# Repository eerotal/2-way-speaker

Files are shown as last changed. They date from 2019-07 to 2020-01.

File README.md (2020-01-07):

Two Way Concrete Speakers
-------------------------

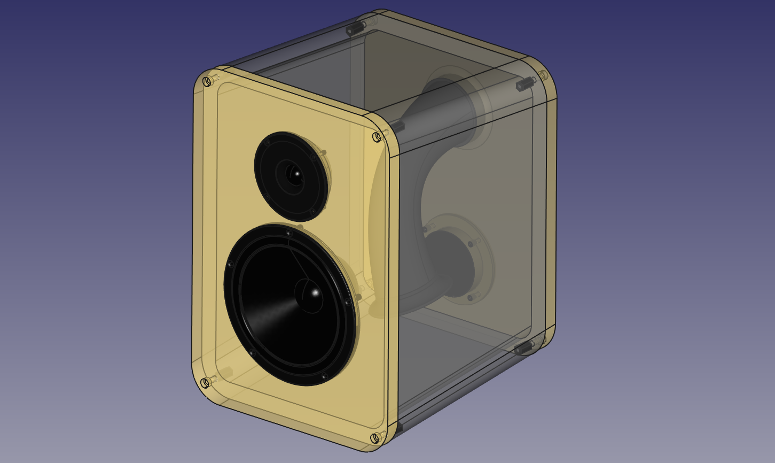
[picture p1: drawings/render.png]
Two Way Speaker


This repository contains all design files for my two way concrete speakers
See the PDF file at `latex/documentation.pdf` for the full documentation.
The PDF file is a concatenated version of all of the exported design files.

The contents of this repository are licensed under the CERN OHL v1.2 license
unless otherwise noted. The full license can be found in the file LICENSE.pdf
in the root of this repository.

License
-------

Copyright Eero Talus 2020.

This documentation describes Open Hardware and is licensed under the CERN OHL
v. 1.2.

You may redistribute and modify this documentation under the terms of the
CERN OHL v.1.2. (http://ohwr.org/cernohl). This documentation is distributed
WITHOUT ANY EXPRESS OR IMPLIED WARRANTY, INCLUDING OF MERCHANTABILITY,
SATISFACTORY QUALITY AND FITNESS FOR A PARTICULAR PURPOSE. Please see the
CERN OHL v.1.2 for applicable conditions.

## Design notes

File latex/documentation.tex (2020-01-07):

\documentclass[10pt]{article}

\usepackage[a4paper,left=20mm, right=20mm, top=20mm, bottom=20mm]{geometry}
\usepackage{pdfpages}
\usepackage{markdown}
\usepackage{multicol}
\usepackage{caption}
\usepackage[none]{hyphenat}

\title{2-way Concrete Speaker Documentation}
\author{Eero Talus}
\date{\today}

\begin{document}
\maketitle
\tableofcontents

\section{License}

\begin{sloppypar}
\noindent
\texttt{Copyright Eero Talus 2020.}\\

\noindent
\texttt{This documentation describes Open Hardware and is licensed under the
CERN OHL v. 1.2.}\\

\noindent
\texttt{You may redistribute and modify this documentation under the terms of
the CERN OHL v.1.2. (http://ohwr.org/cernohl). This documentation is distributed
WITHOUT ANY EXPRESS OR IMPLIED WARRANTY, INCLUDING OF MERCHANTABILITY,
SATISFACTORY QUALITY AND FITNESS FOR A PARTICULAR PURPOSE. Please see the
CERN OHL v.1.2 for applicable conditions.}
\end{sloppypar}

\section{Introduction}

\noindent This PDF contains documentation for my self designed vented two way
speakers. All the design files can be found from the GIT repository at
\url{https://github.com/eerotal/2-way-speaker}. Below is a 3D render of the
speakers.\\

\begin{figure}[htp]
	\centering
	
	\caption{3D render of the speaker.}
\end{figure}

\begin{figure}[htp]
	\centering
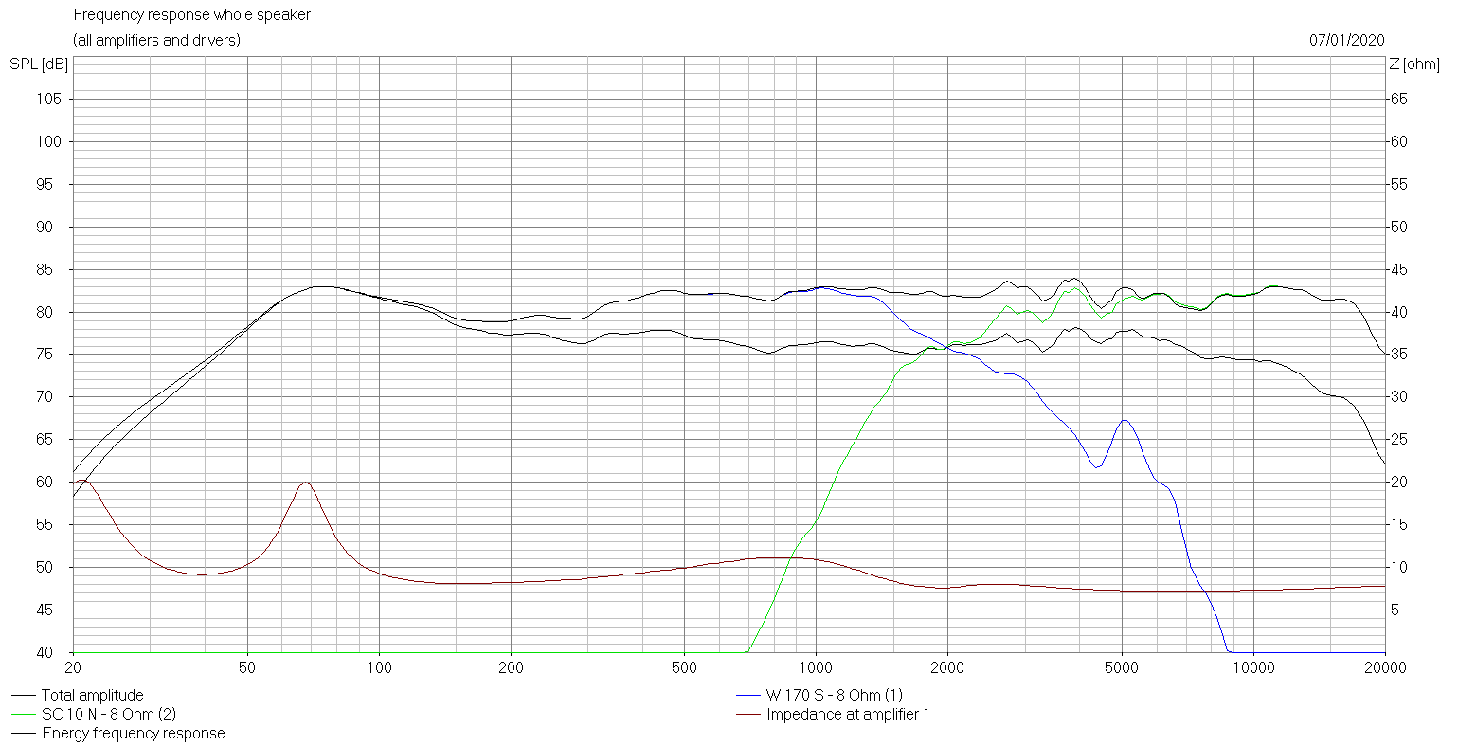
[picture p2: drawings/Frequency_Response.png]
	
	\caption{Speaker frequency response graph.}
\end{figure}

\pagebreak

\noindent The speaker specifications are:

\begin{itemize}
\item Cabinet volume (V): 20 l
\item Cabinet tuning frequenxy (Fb): 42.49 Hz
\item Woofer: Visaton W-170 S 8Ohm
\item Tweeter: Visaton SC-10 N
\end{itemize}

\noindent The speaker cabinet was designed to have a frequency response that's
as flat as possible over the entire bandwidth of the speaker. The cabinet
features a theoretically optimal reflex port designed based on various research
papers on the subject. The cabinet is constructed from concrete and wood to
increase its mass and to improve speaker performance.\\

\noindent The speaker uses a crossover circuit made using third order
Butterworth filters. Speaker impedance and sensitivity matching was also taken
into account while desiging the filter. All design and documentation files were
created using open file formats, tools and technologies.\\

\noindent You can run the shell script \texttt makedocs.sh to generate this
PDF file.

\section{Respository directory structure}

\begin{itemize}
\item 2-way-speaker
    \begin{itemize}
    \item crossover
        \begin{itemize}
        \item KiCad
            \begin{itemize}
            \item \textit{Crossover schematics and PCB design files.}
            \end{itemize}
        \item ngspice
            \begin{itemize}
            \item \textit{NgSpice crossover simulation files.}
            \end{itemize}
        \end{itemize}
    \item docs
        \begin{itemize}
        \item \textit{Documentation files.}
        \end{itemize}
    \item latex
        \begin{itemize}
        \item \textit{LaTeX files for concatenating all documentation files into one PDF.}
        \end{itemize}
    \item math
        \begin{itemize}
        \item \textit{WxMaxima design calculations.}
        \end{itemize}
    \item models
        \begin{itemize}
        \item \textit{FreeCAD 3D design files.}
        \end{itemize}
    \item simulation
        \begin{itemize}
        \item \textit{Visaton Boxsim simulation files.}
        \end{itemize}
    \end{itemize}
\end{itemize}

\section{Software and technologies}

Below is a list of the software and technologies used in this project.

\begin{itemize}
\item KiCad: Crossover electronics design.
\item ngspice: Crossover circuit simulation.
\item FreeCAD: 3D models and mechanical drawings.
\item Boxsim: Speaker simulation.
\item wxMaxima: Design calculations.
\item LaTeX: Documentation
\end{itemize}

\pagebreak
\null
\vfil
\centering\section{Mechanical drawings}
\vfil
\pagebreak
\includepdf[landscape=true]{../drawings/Front_Plate_Drawing.pdf}
\includepdf[landscape=true]{../drawings/Back_Plate_Drawing.pdf}
\includepdf[landscape=true]{../drawings/Shell_Drawing.pdf}
\includepdf[landscape=true]{../drawings/Port_Drawing.pdf}

\pagebreak
\null
\vfil
\centering\section{Crossover schematic and simulation graphs}
\vfil
\pagebreak
\includepdf[landscape=true]{../drawings/Crossover_Schematic.pdf}
\begin{multicols}{2}
	
	
	
	
	
\end{multicols}

\end{document}

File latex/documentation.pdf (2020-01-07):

# 2-way Concrete Speaker Documentation

Eero Talus

January 7, 2020

## Contents

1 License | 1
2 Introduction | 1
3 Respository directory structure | 3
4 Software and technologies | 3
5 Mechanical drawings | 4
6 Crossover schematic and simulation graphs | 9

## 1 License

Copyright Eero Talus 2020.

This documentation describes Open Hardware and is licensed under the CERN OHL v. 1.2.

You may redistribute and modify this documentation under the terms of the CERN OHL v.1.2. (http://ohwr.org/cernohl). This documentation is distributed WITHOUT ANY EXPRESS OR IMPLIED WARRANTY, INCLUDING OF MERCHANTABILITY, SATISFACTORY QUALITY AND FITNESS FOR A PARTICULAR PURPOSE. Please see the CERN OHL v.1.2 for applicable conditions.

## 2 Introduction

This PDF contains documentation for my self designed vented two way speakers. All the design files can be found from the GIT repository at https://github.com/eerotal/2-way-speaker. Below is a 3D render of the speakers.

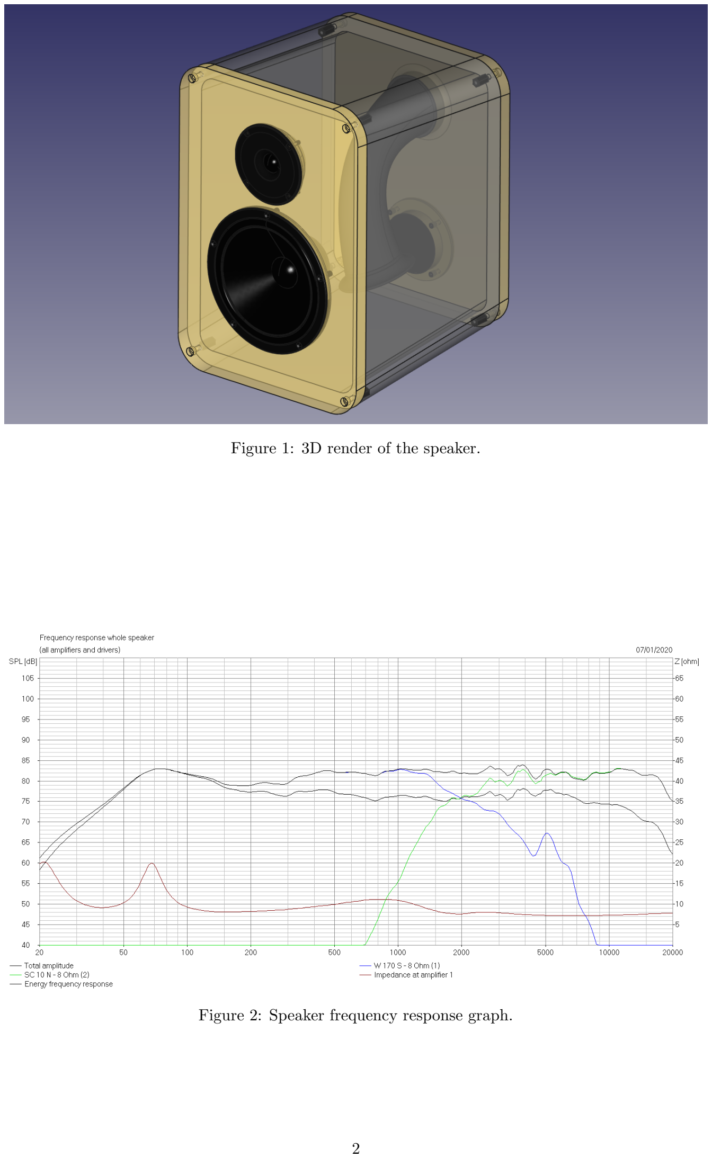
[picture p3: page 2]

Figure 1: 3D render of the speaker.

Figure 2: Speaker frequency response graph.

The speaker specifications are:

- Cabinet volume (V): 20 l
- Cabinet tuning frequenxy (Fb): 42.49 Hz
- Woofer: Visaton W-170 S 8Ohm
- Tweeter: Visaton SC-10 N

The speaker cabinet was designed to have a frequency response that’s as flat as possible over the entire bandwidth of the speaker. The cabinet features a theoretically optimal reflex port designed based on various research papers on the subject. The cabinet is constructed from concrete and wood to increase its mass and to improve speaker performance.

The speaker uses a crossover circuit made using third order Butterworth filters. Speaker impedance and sensitivity matching was also taken into account while desiging the filter. All design and documentation files were created using open file formats, tools and technologies.

You can run the shell script makedocs.sh to generate this PDF file.

## 3 Respository directory structure

- 2-way-speaker

– crossover
∗ KiCad
- Crossover schematics and PCB design files. ∗ ngspice
- NgSpice crossover simulation files.

– docs
∗ Documentation files.

– latex
∗ LaTeX files for concatenating all documentation files into one PDF.

– math
∗ WxMaxima design calculations.

– models
∗ FreeCAD 3D design files.

– simulation
∗ Visaton Boxsim simulation files.

## 4 Software and technologies

Below is a list of the software and technologies used in this project.

- KiCad: Crossover electronics design.
- ngspice: Crossover circuit simulation.
- FreeCAD: 3D models and mechanical drawings.
- Boxsim: Speaker simulation.
- wxMaxima: Design calculations.
- LaTeX: Documentation

## 5 Mechanical drawings

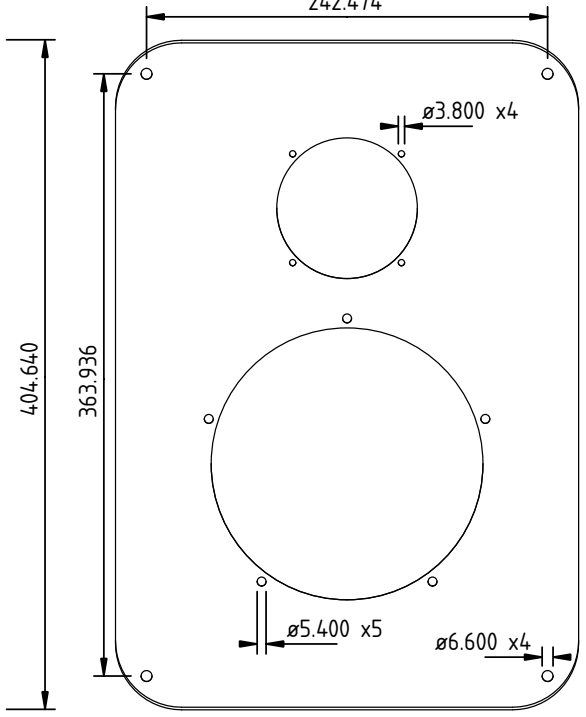
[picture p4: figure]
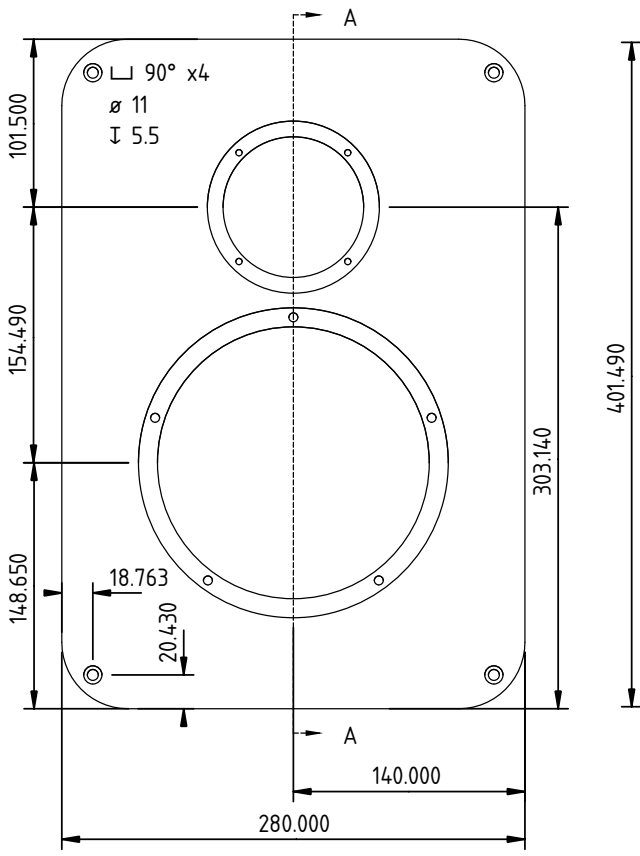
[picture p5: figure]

95.0

18.000

242.474

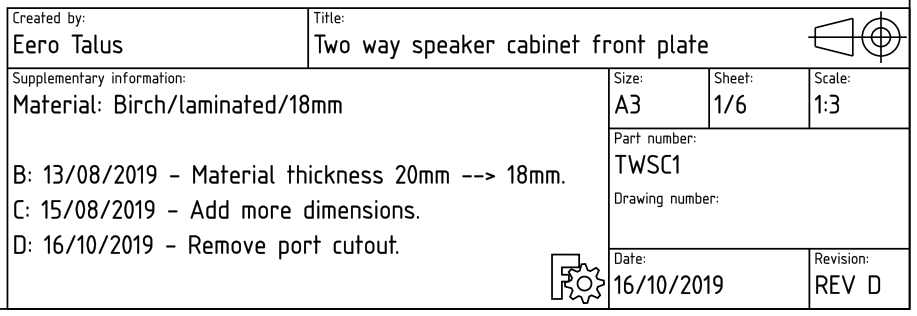
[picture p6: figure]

3D - 1:8

(*1) Tweeter mount holes (M3) are evenly spaced on a ø93.00mm circle. (*2) Woofer mount holes (M4) are evenly spaced on a ø175.80mm circle. (*3) Port cutout edges filleted with radius 8.00mm.
(*4) Front plate perimeter filleted with radius 2.00mm.
(*5) Front plate corner radius 40.00mm.

# Section A - A

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
7.000

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
3.000

Copyright Eero Talus 2019
This documentation describes Open Hardware and is licensed under the CERN OHL v. 1.2.
You may redistribute and modify this documentation under the terms of the CERN OHL v.1.2. (http://ohwr.org/cernohl). This documentation is distributed WITHOUT ANY EXPRESS OR IMPLIED WARRANTY, INCLUDING OF MERCHANTABILITY, SATISFACTORY QUALITY AND FITNESS FOR A PARTICULAR PURPOSE. Please see the CERN OHL v.1.2 for applicable conditions.

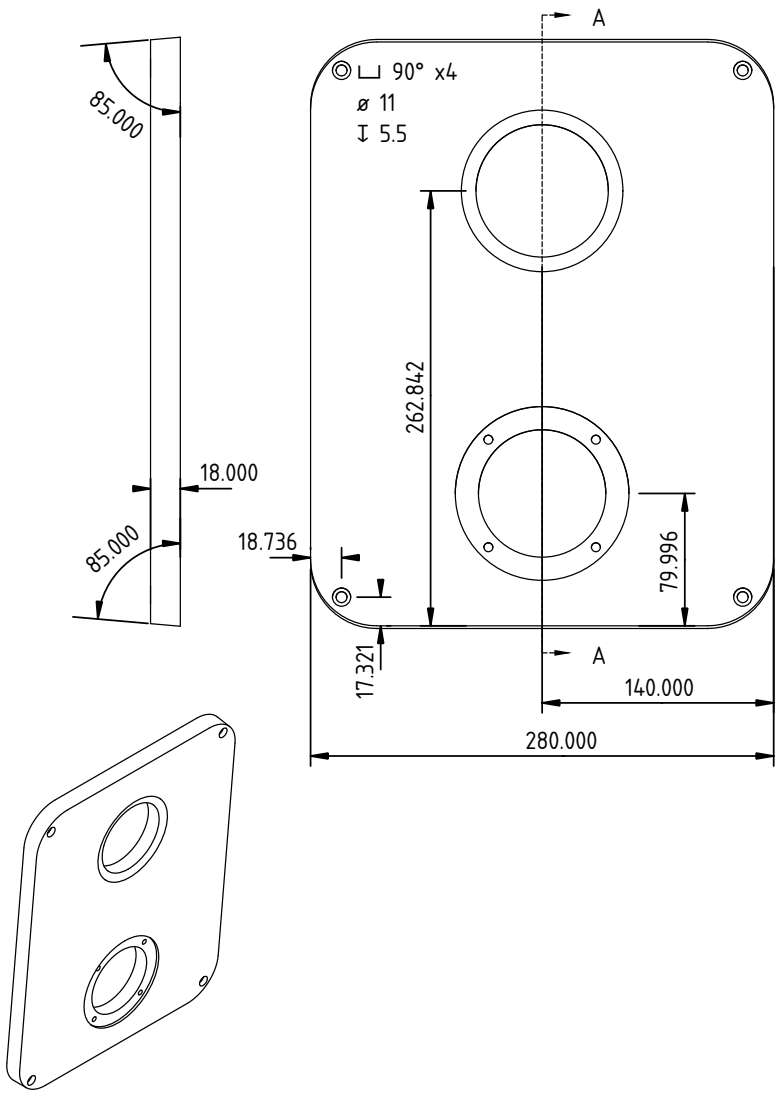
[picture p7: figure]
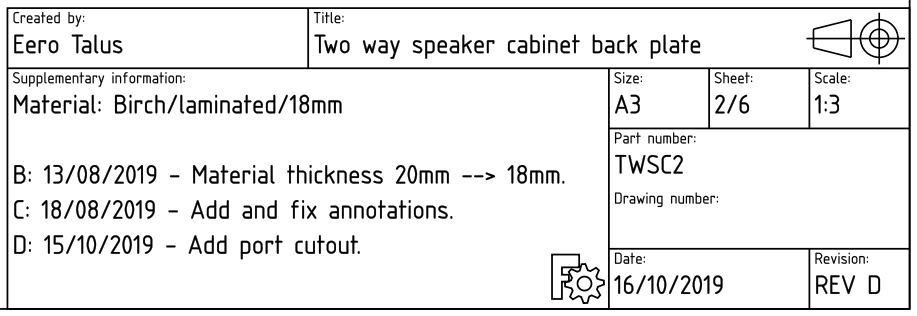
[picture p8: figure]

3D - 1:5

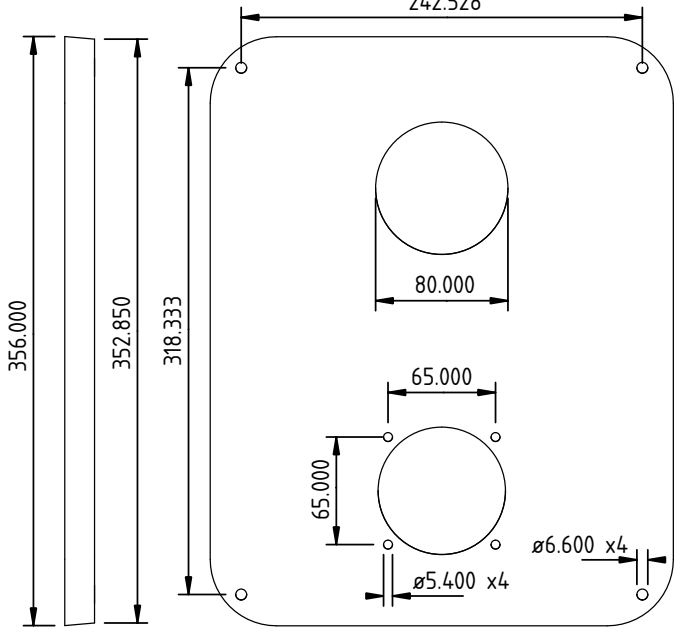
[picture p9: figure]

242.528

(*1) Connector terminal mount holes (M3) are evenly spaced on a ø91.92mm circle.

# Section A - A

18.000

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
3.000

R15.000

(*2) Back plate perimeter filleted with radius 2.00mm. (*3) Back plate corner radius 40.00mm.

Copyright Eero Talus 2019
This documentation describes Open Hardware and is licensed under the CERN OHL v. 1.2.
You may redistribute and modify this documentation under the terms of the CERN OHL v.1.2. (http://ohwr.org/cernohl). This documentation is distributed WITHOUT ANY EXPRESS OR IMPLIED WARRANTY, INCLUDING OF MERCHANTABILITY, SATISFACTORY QUALITY AND FITNESS FOR A PARTICULAR PURPOSE. Please see the CERN OHL v.1.2 for applicable conditions.

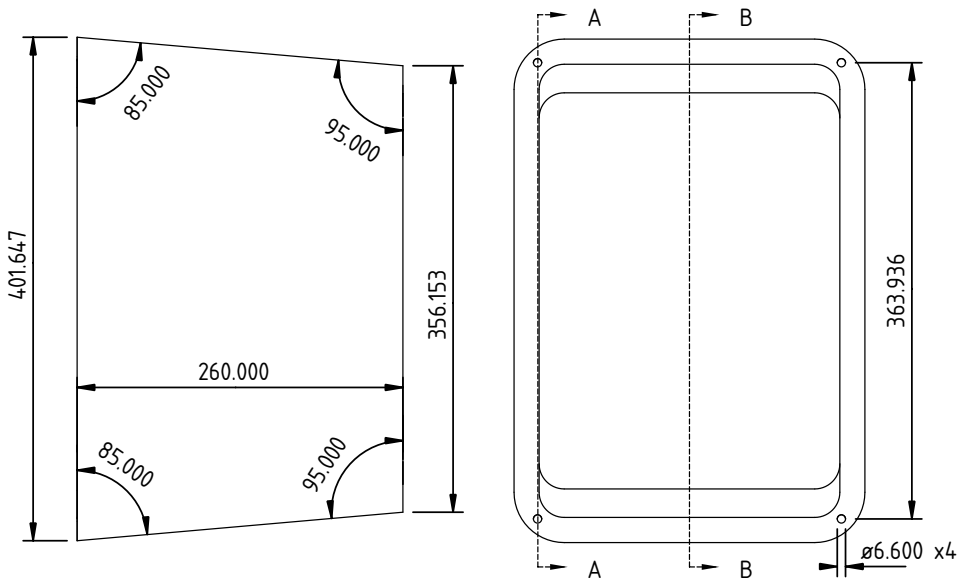
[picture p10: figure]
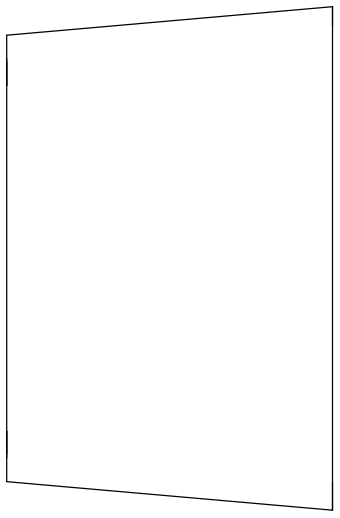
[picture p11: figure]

ø6.600 X4

3

6

3.9

3

6

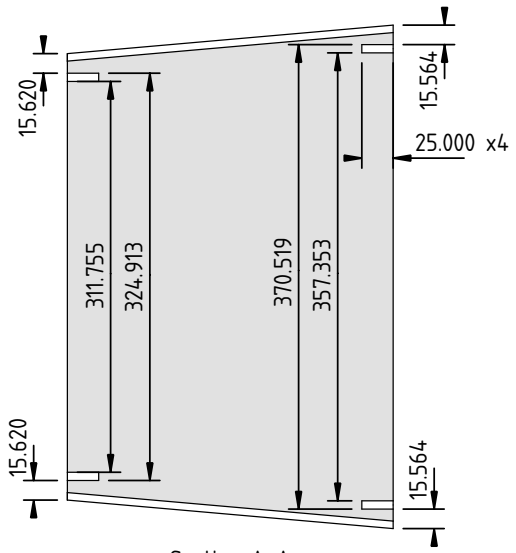
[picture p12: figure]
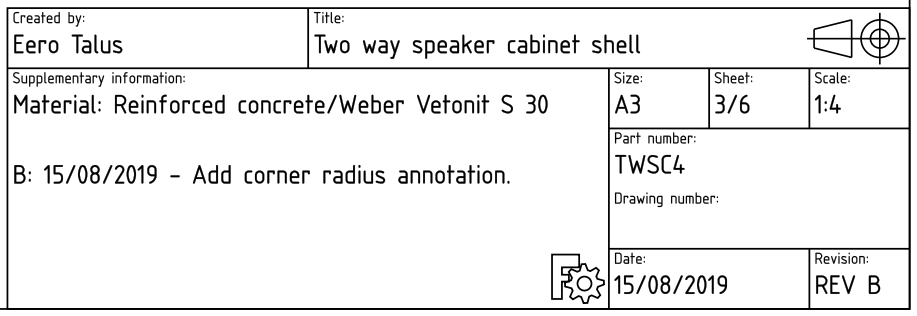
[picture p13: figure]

# Section A-A

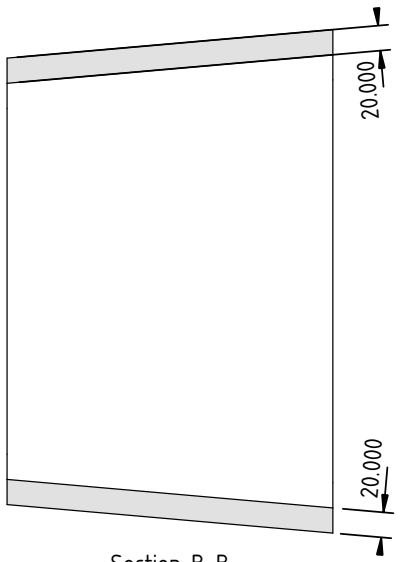
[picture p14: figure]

# Section B-B

3D - 1:8

(*1) Shell corner radius 40.00mm outside and 20.00mm inside.

Copyright Eero Talus 2019
This documentation describes Open Hardware and is licensed under the CERN OHL v. 1.2.
You may redistribute and modify this documentation under the terms of the CERN OHL v.1.2. (http://ohwr.org/cernohl). This documentation is distributed WITHOUT ANY EXPRESS OR IMPLIED WARRANTY, INCLUDING OF MERCHANTABILITY, SATISFACTORY QUALITY AND FITNESS FOR A PARTICULAR PURPOSE. Please see the CERN OHL v.1.2 for applicable conditions.

# (*1) The reflex port is printed in four pieces. Both flares are printed separetely and the main tube is split into two

pieces. These are then glued together after printing.

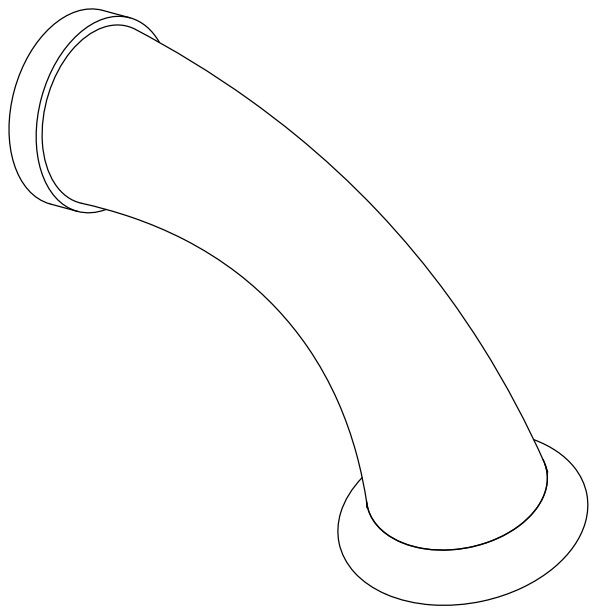
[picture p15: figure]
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

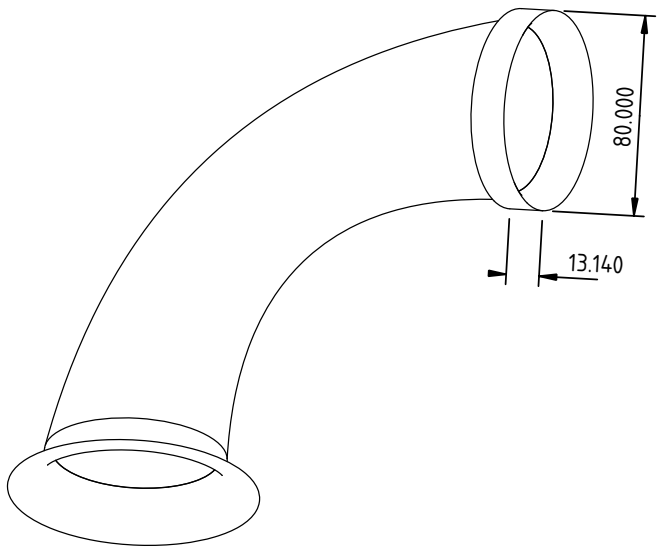
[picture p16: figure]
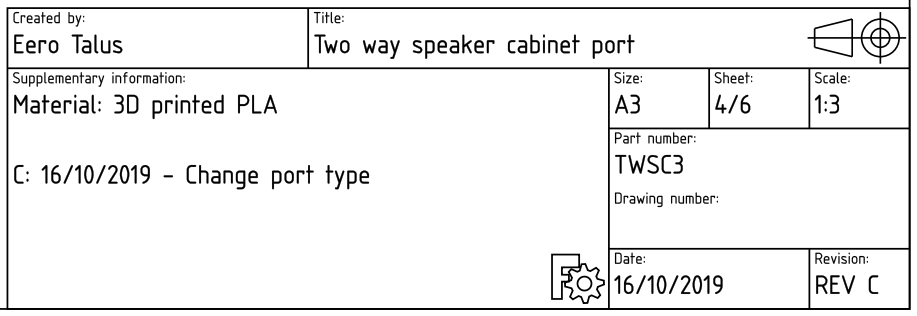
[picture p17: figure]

## 6 Crossover schematic and simulation graphs

H4 C2

## 10uH2 H1

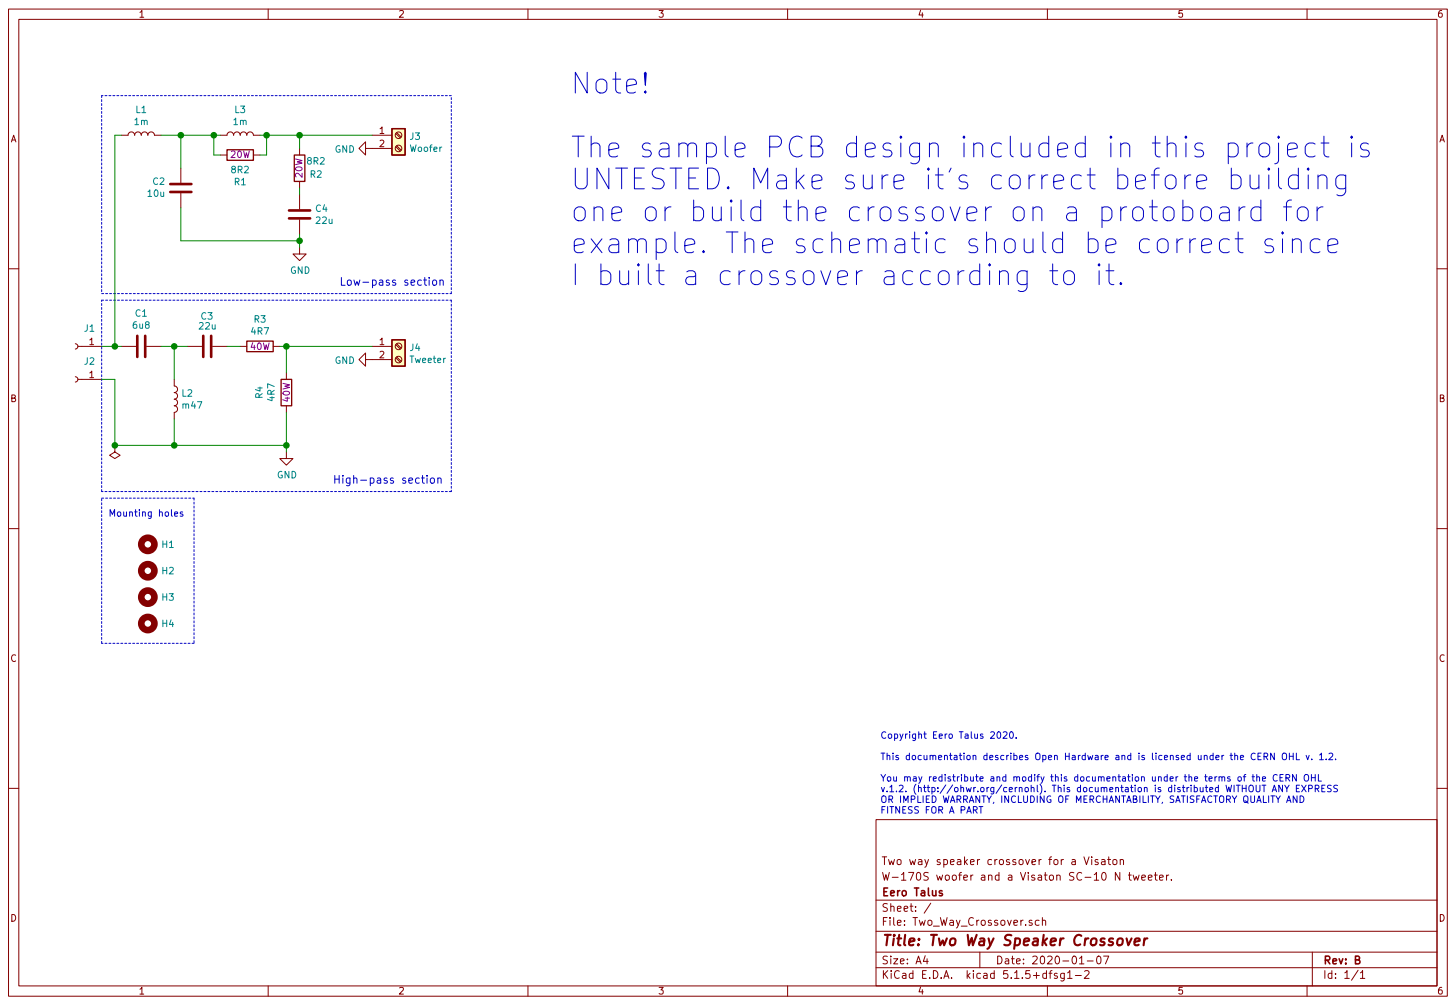
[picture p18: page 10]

The sample PCB design included in this project is
UNTESTED. Make sure it's correct before building
one or build the crossover on a protoboard for
example. The schematic should be correct since
I built a crossover according to it.

This documentation describes Open Hardware and is licensed under the CERN OHL v. 1.2.

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

Id: 1/1 Title: Two Way Speaker Crossover

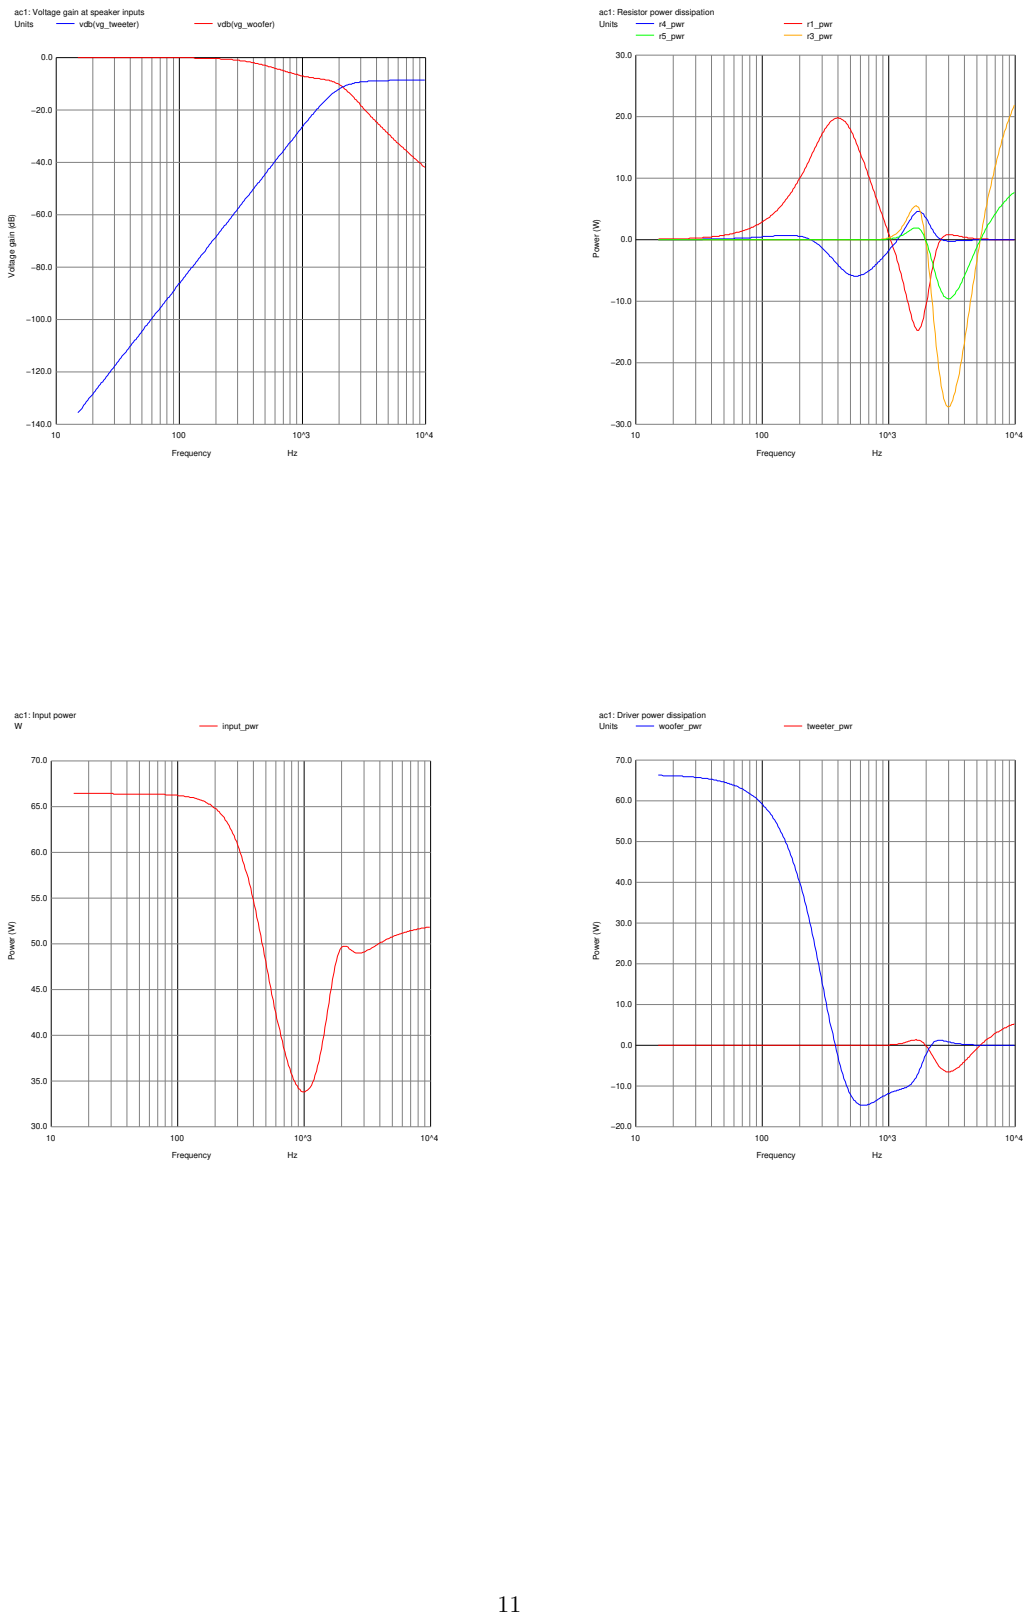
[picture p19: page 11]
Frequency; Units; vdb(vg_tweeter); vdb(vg_woofer); Power (W); ac1: Input power; input_pwr; r4_pwr; r1_pwr; r5_pwr; r3_pwr; woofer_pwr; tweeter_pwr

ac1: Voltage gain at speaker inputs

ac1: Resistor power dissipation

Voltage gain (dB)

ac1: Driver power dissipation

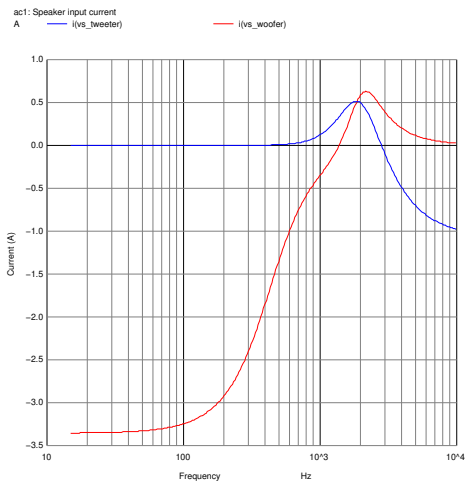
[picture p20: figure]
Frequency; Current (A); ac1: Speaker input current; i(vs_tweeter); i(vs_woofer)

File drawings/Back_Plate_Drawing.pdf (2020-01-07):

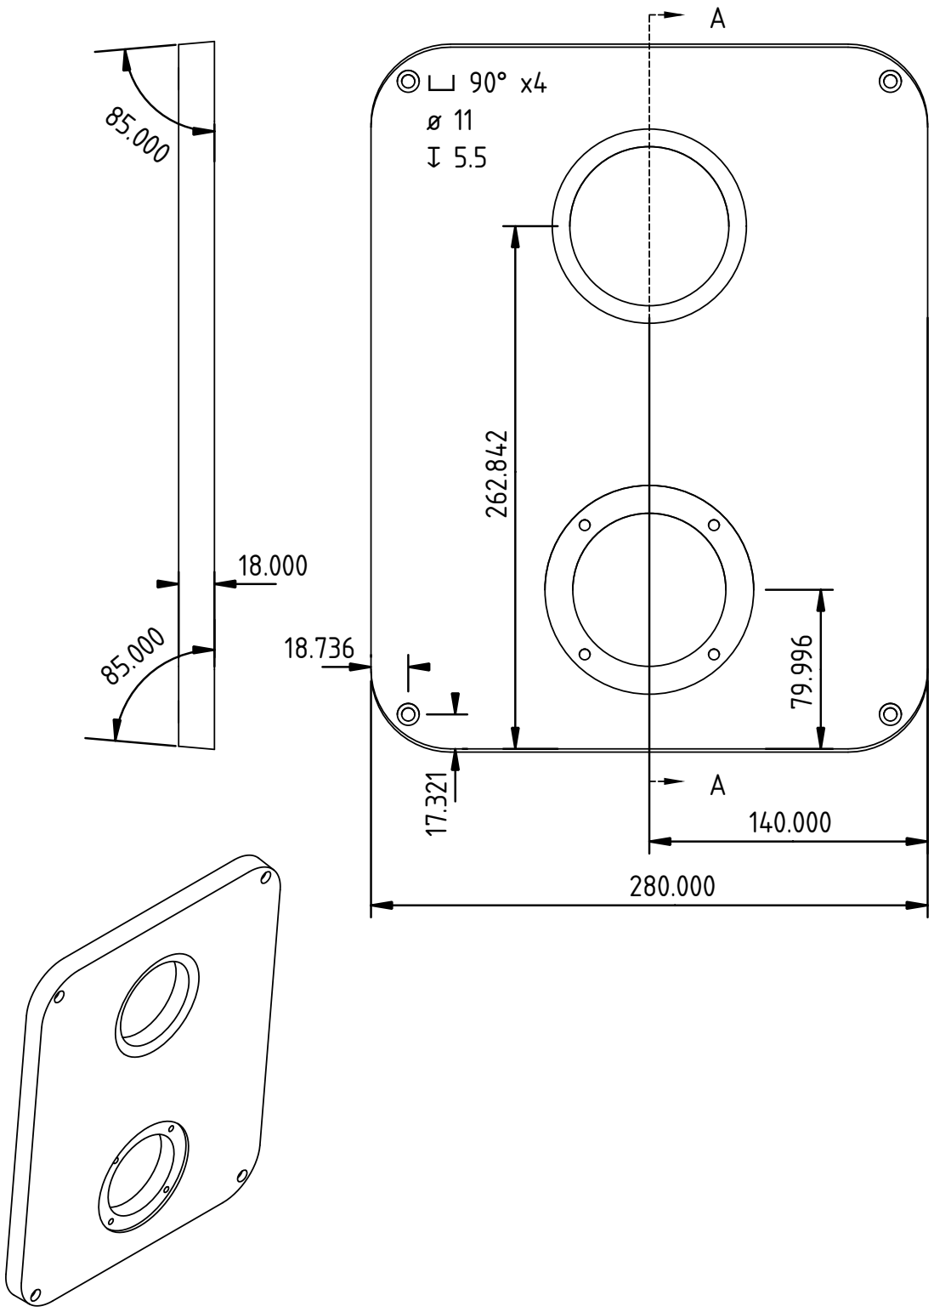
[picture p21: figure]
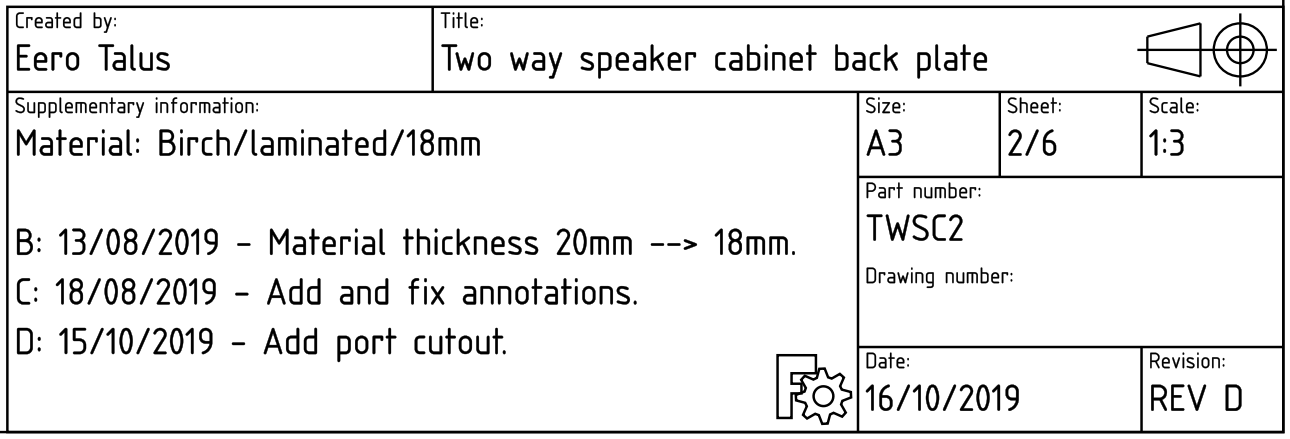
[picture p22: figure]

3D - 1:5

242.528

(*1) Connector terminal mount holes (M3) are evenly spaced on a ø91.92mm circle.

## Section A - A

18.000

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
3.000

R15.000

(*2) Back plate perimeter filleted with radius 2.00mm. (*3) Back plate corner radius 40.00mm.

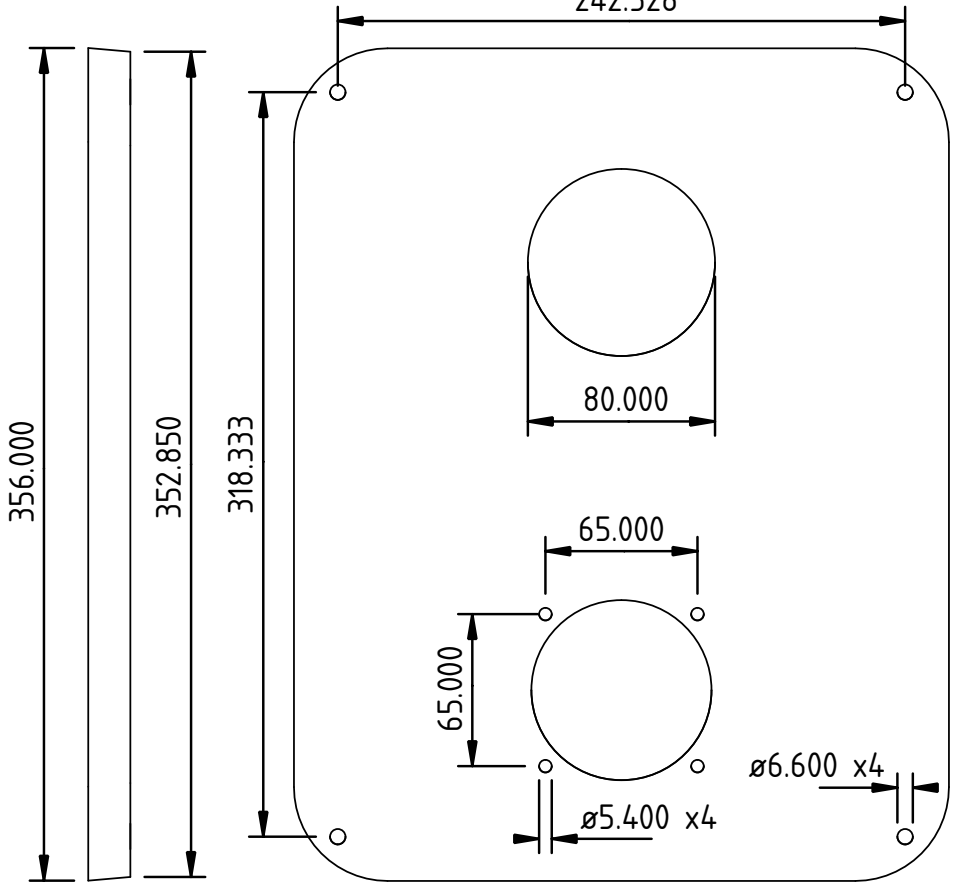
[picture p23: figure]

Copyright Eero Talus 2019
This documentation describes Open Hardware and is licensed under the CERN OHL v. 1.2.
You may redistribute and modify this documentation under the terms of the CERN OHL v.1.2. (http://ohwr.org/cernohl). This documentation is distributed WITHOUT ANY EXPRESS OR IMPLIED WARRANTY, INCLUDING OF MERCHANTABILITY, SATISFACTORY QUALITY AND FITNESS FOR A PARTICULAR PURPOSE. Please see the CERN OHL v.1.2 for applicable conditions.

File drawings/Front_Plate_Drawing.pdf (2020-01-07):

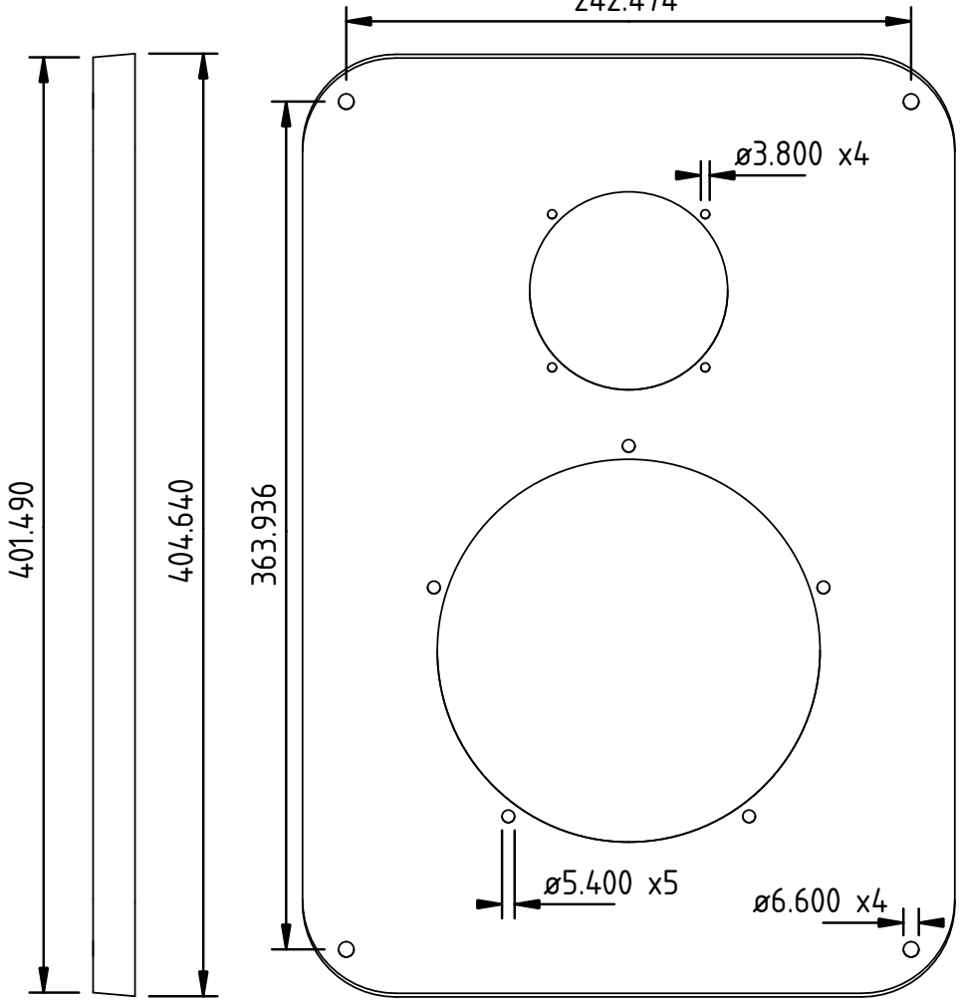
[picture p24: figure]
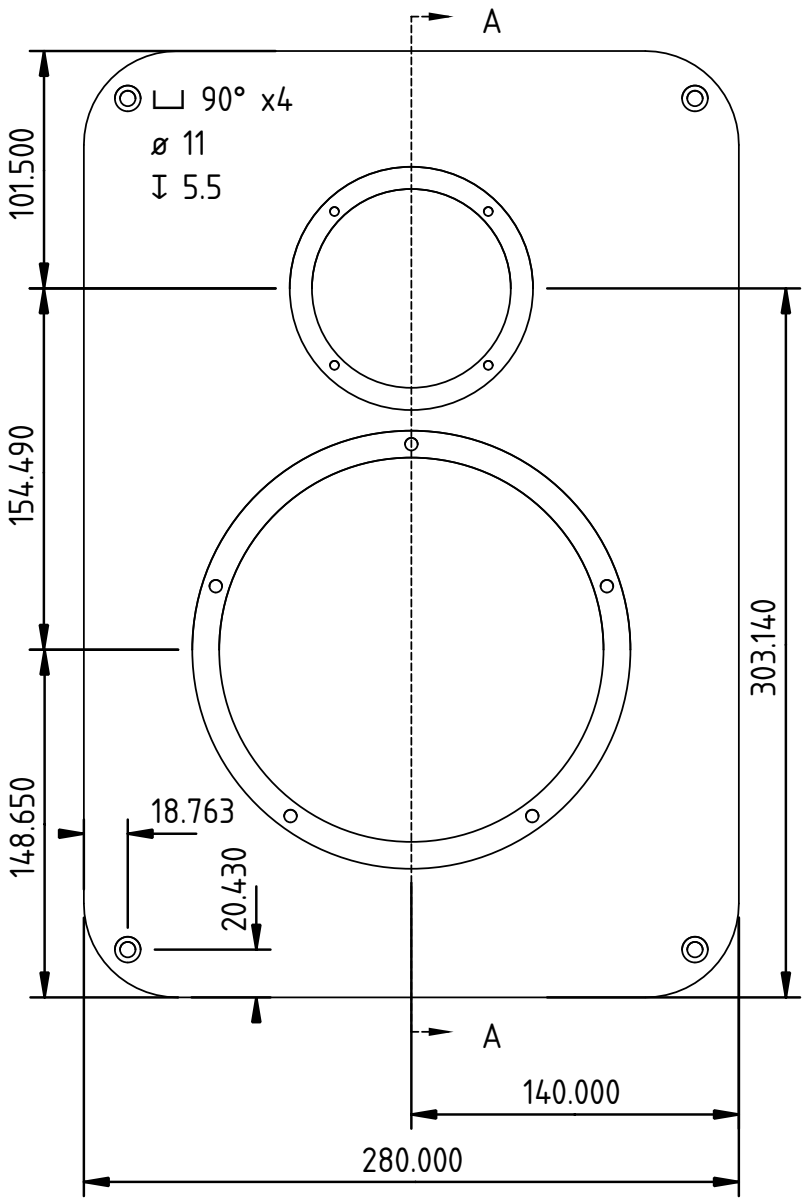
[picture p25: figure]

95.0

18.000

242.474


3D - 1:8

(*1) Tweeter mount holes (M3) are evenly spaced on a ø93.00mm circle. (*2) Woofer mount holes (M4) are evenly spaced on a ø175.80mm circle. (*3) Port cutout edges filleted with radius 8.00mm.
(*4) Front plate perimeter filleted with radius 2.00mm.
(*5) Front plate corner radius 40.00mm.

## Section A - A

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
7.000

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
3.000

Copyright Eero Talus 2019
This documentation describes Open Hardware and is licensed under the CERN OHL v. 1.2.
You may redistribute and modify this documentation under the terms of the CERN OHL v.1.2. (http://ohwr.org/cernohl). This documentation is distributed WITHOUT ANY EXPRESS OR IMPLIED WARRANTY, INCLUDING OF MERCHANTABILITY, SATISFACTORY QUALITY AND FITNESS FOR A PARTICULAR PURPOSE. Please see the CERN OHL v.1.2 for applicable conditions.

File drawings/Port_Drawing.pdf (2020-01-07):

## (*1) The reflex port is printed in four pieces. Both flares are printed separetely and the main tube is split into two

pieces. These are then glued together after printing.


Copyright Eero Talus 2019
This documentation describes Open Hardware and is licensed under the CERN OHL v. 1.2.
You may redistribute and modify this documentation under the terms of the CERN OHL v.1.2. (http://ohwr.org/cernohl). This documentation is distributed WITHOUT ANY EXPRESS OR IMPLIED WARRANTY, INCLUDING OF MERCHANTABILITY, SATISFACTORY QUALITY AND FITNESS FOR A PARTICULAR PURPOSE. Please see the CERN OHL v.1.2 for applicable conditions.


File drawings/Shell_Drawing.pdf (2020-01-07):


ø6.600 X4


3

6

3.9

3

6


## Section A-A


## Section B-B

3D - 1:8

(*1) Shell corner radius 40.00mm outside and 20.00mm inside.

Copyright Eero Talus 2019
This documentation describes Open Hardware and is licensed under the CERN OHL v. 1.2.
You may redistribute and modify this documentation under the terms of the CERN OHL v.1.2. (http://ohwr.org/cernohl). This documentation is distributed WITHOUT ANY EXPRESS OR IMPLIED WARRANTY, INCLUDING OF MERCHANTABILITY, SATISFACTORY QUALITY AND FITNESS FOR A PARTICULAR PURPOSE. Please see the CERN OHL v.1.2 for applicable conditions.

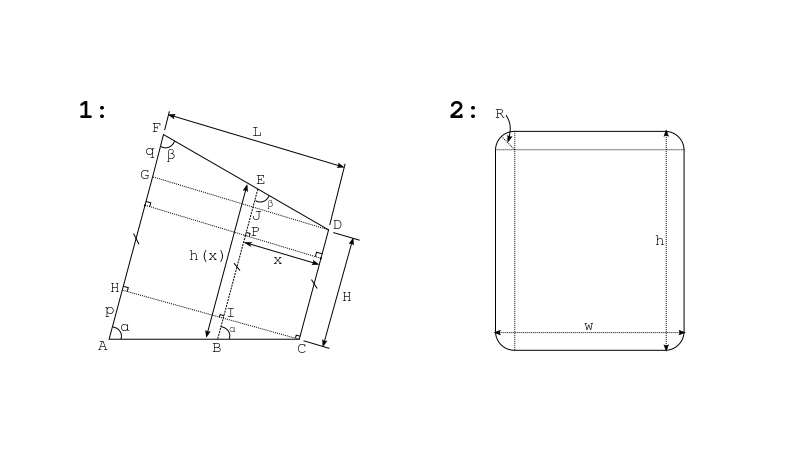
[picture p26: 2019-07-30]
math/drawing.png

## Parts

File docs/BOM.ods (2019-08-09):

Part | Value | Qty | €/pc. | €/tot |  | Ordered
Monacor ST-960GM | N/A | 1 | 5.95000 | 5.9500 | € | Y
Visaton W-170 S 8ohm | N/A | 1 | 36.00000 | 36.0000 | € | Y
Visaton SC-10 N | N/A | 1 | 19.00000 | 19.0000 | € | Y
Bossard BN1054/M4 | N/A | 9 | 0.19390 | 1.7451 | € | N
Bossard BN1054/M3 | N/A | 4 | 0.09440 | 0.3776 | € | N
Visaton 4986 | 1mH | 2 | 4.13000 | 8.2600 | € | N
Visaton 4993 | 0.47mH | 1 | 3.46000 | 3.4600 | € | N
Wima MKS4C051005F00KSSD | 10uF | 2 | 2.20000 | 4.4000 | € | N
Wima MKS4D052206F00KSSD | 22uF | 1 | 4.21500 | 4.2150 | € | N
Wima MKS4D046806B00KSSD | 6.8uF | 1 | 1.81500 | 1.8150 | € | N
Royal Ohm PRW020JW82JB00 | 8.2Ohm | 6 | 0.54170 | 3.2502 | € | N
Total |  |  |  | 88.4729 | €
Total for two |  |  |  | 176.9458 | €

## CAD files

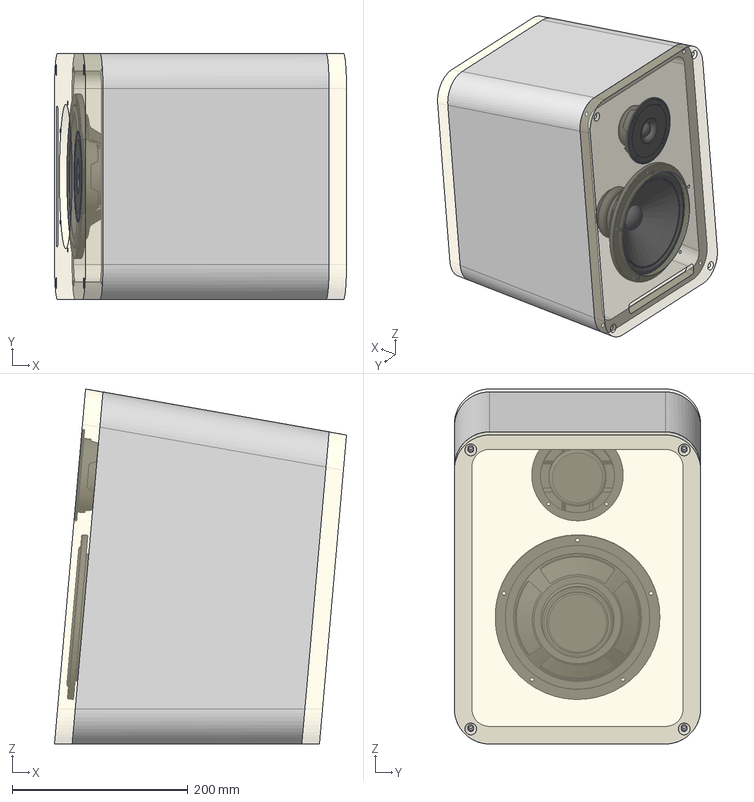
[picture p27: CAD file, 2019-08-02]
model.FCStd
331.9 x 280.0 x 403.4 mm
Front_plate
Back_plate
Port
m6_long_bolt_body003
m6_long_bolt_body002
m6_long_bolt_body001
m6_long_bolt_body
Visaton_W-170_S_Metalwork
Visaton_W-170_S_Cone
Visaton_SC-10_N_Body
Visaton_SC-10_N_Dome

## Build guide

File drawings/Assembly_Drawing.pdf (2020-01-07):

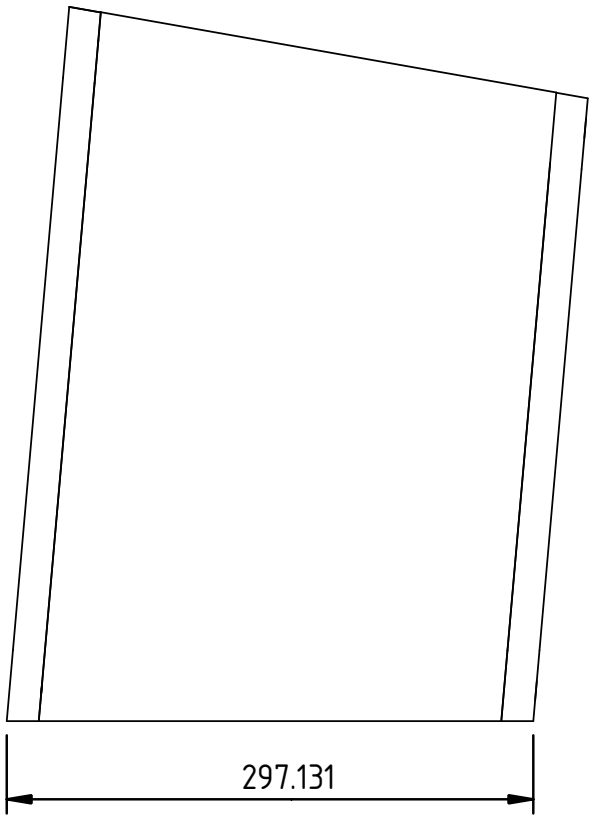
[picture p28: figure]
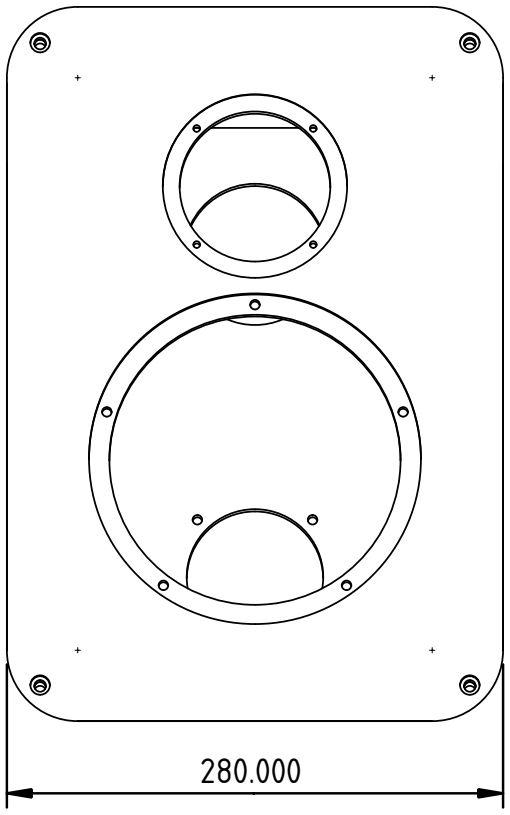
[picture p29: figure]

297.131 280.000

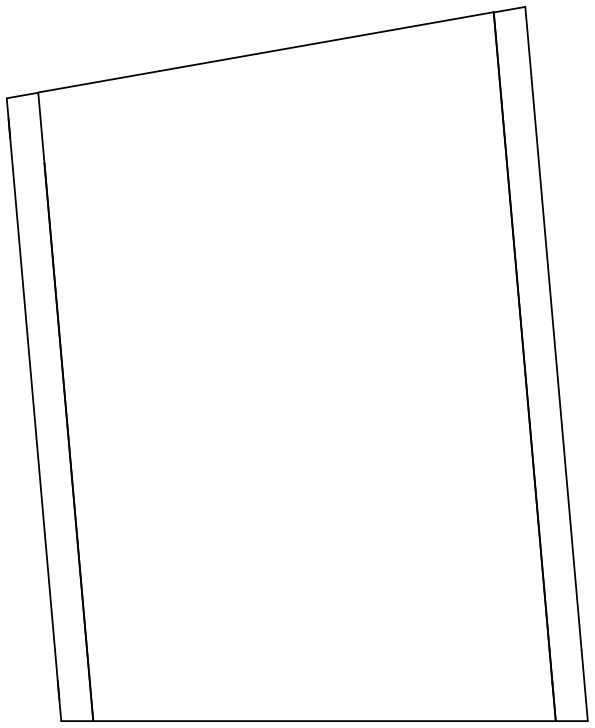
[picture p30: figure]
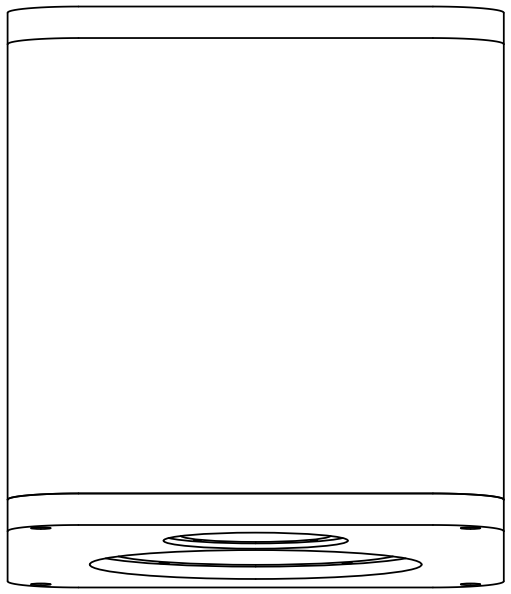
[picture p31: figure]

Copyright Eero Talus 2019

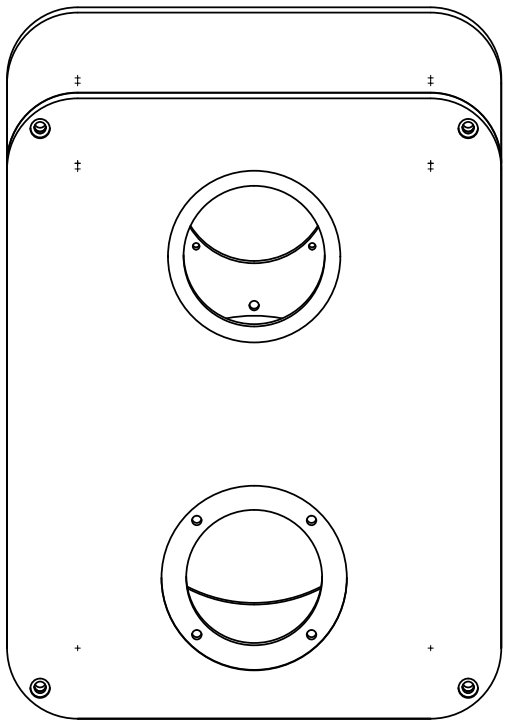
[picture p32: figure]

This documentation describes Open Hardware and is licensed under the CERN OHL v. 1.2.
You may redistribute and modify this documentation under the terms of the CERN OHL v.1.2. (http://ohwr.org/cernohl). This documentation is distributed WITHOUT ANY EXPRESS OR IMPLIED WARRANTY, INCLUDING OF MERCHANTABILITY, SATISFACTORY QUALITY AND FITNESS FOR A PARTICULAR PURPOSE. Please see the CERN OHL v.1.2 for applicable conditions.

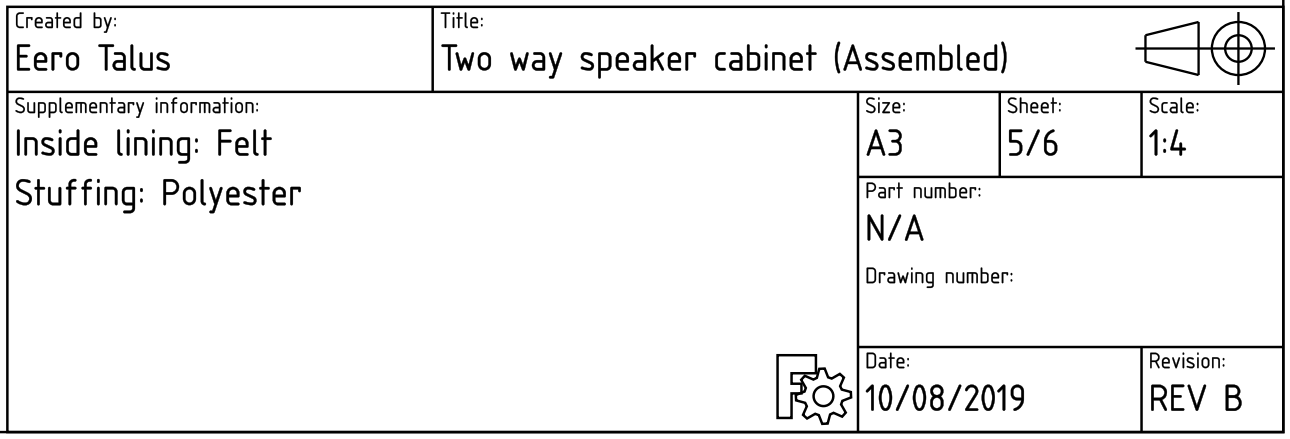
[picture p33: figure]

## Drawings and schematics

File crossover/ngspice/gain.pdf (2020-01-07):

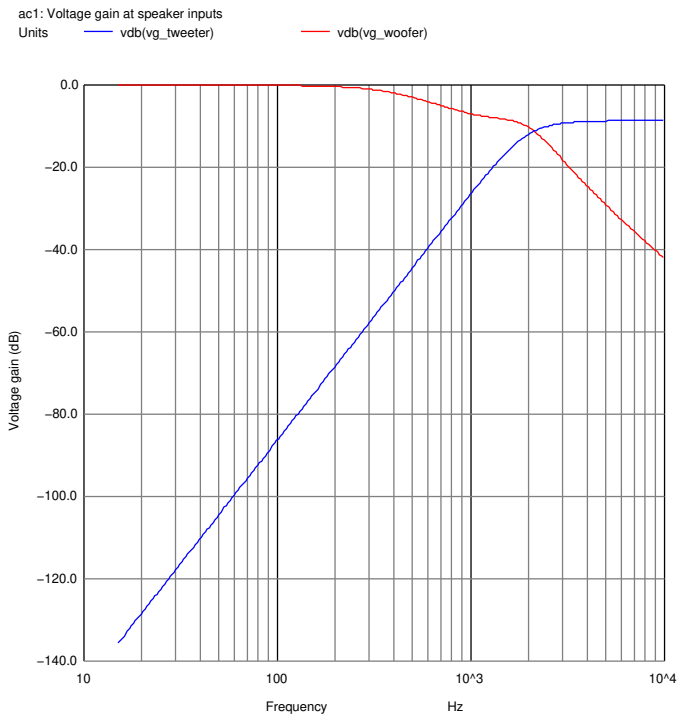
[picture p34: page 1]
Frequency; Units; vdb(vg_tweeter); vdb(vg_woofer)

ac1: Voltage gain at speaker inputs

Voltage gain (dB)

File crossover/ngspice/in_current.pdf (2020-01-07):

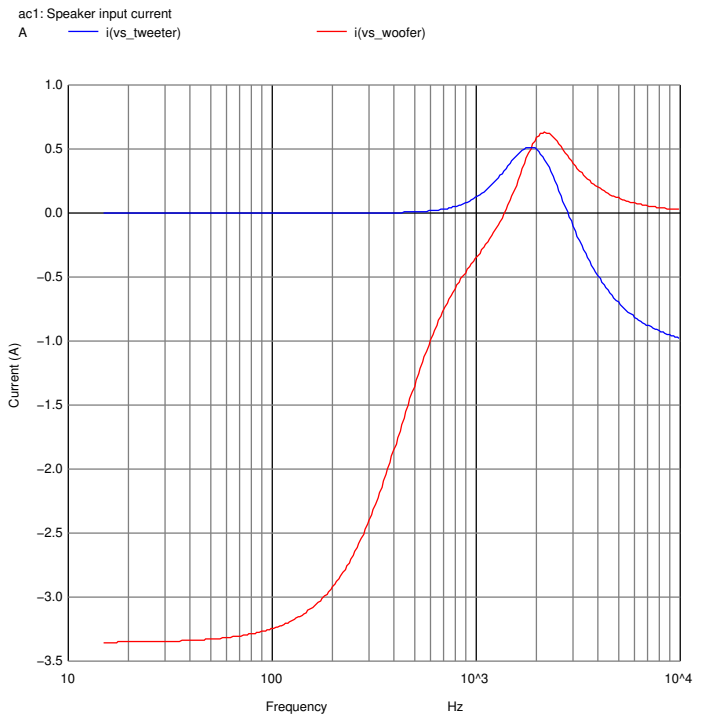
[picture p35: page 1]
Frequency; Current (A); i(vs_tweeter); i(vs_woofer)

ac1: Speaker input current

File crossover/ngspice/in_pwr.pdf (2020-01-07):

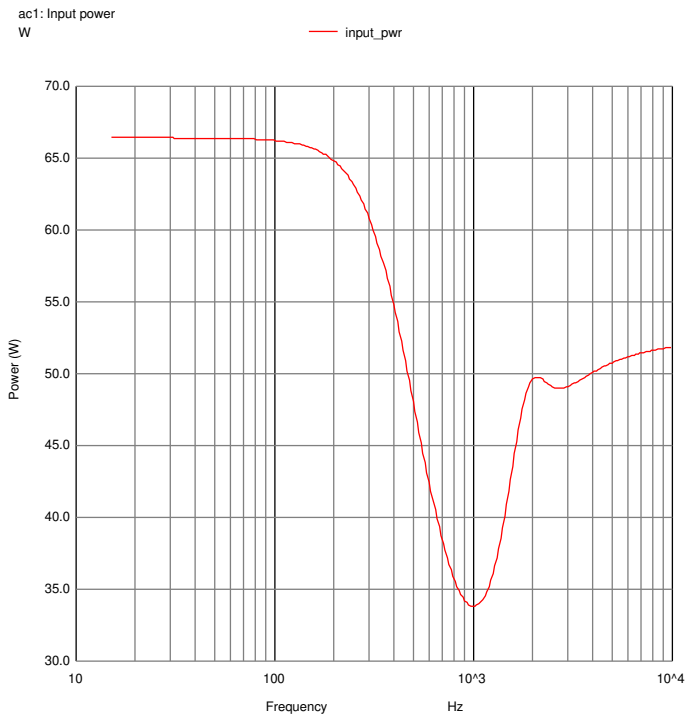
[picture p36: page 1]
Frequency; Power (W); ac1: Input power; input_pwr

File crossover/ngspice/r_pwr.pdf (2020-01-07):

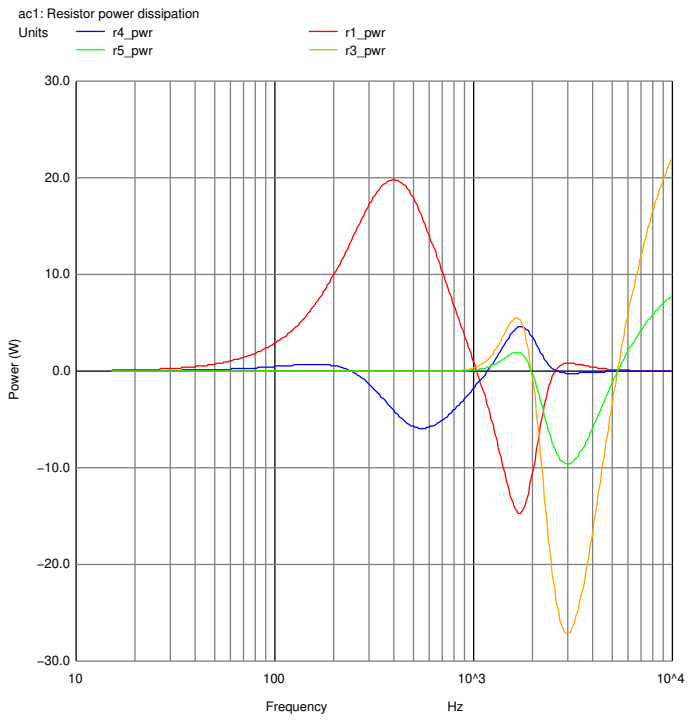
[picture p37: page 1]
Frequency; Power (W); Units; r4_pwr; r1_pwr; r5_pwr; r3_pwr

ac1: Resistor power dissipation

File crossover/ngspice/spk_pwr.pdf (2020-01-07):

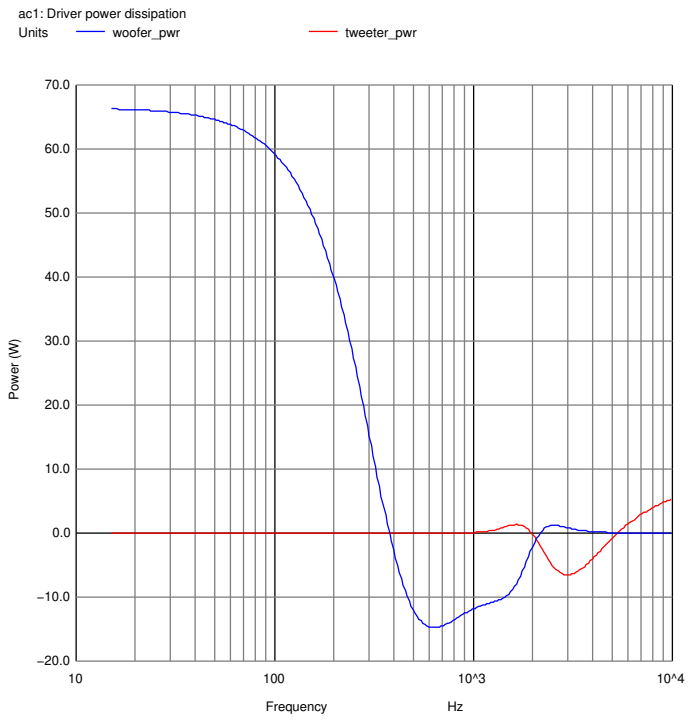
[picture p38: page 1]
Frequency; Power (W); Units; woofer_pwr; tweeter_pwr

ac1: Driver power dissipation

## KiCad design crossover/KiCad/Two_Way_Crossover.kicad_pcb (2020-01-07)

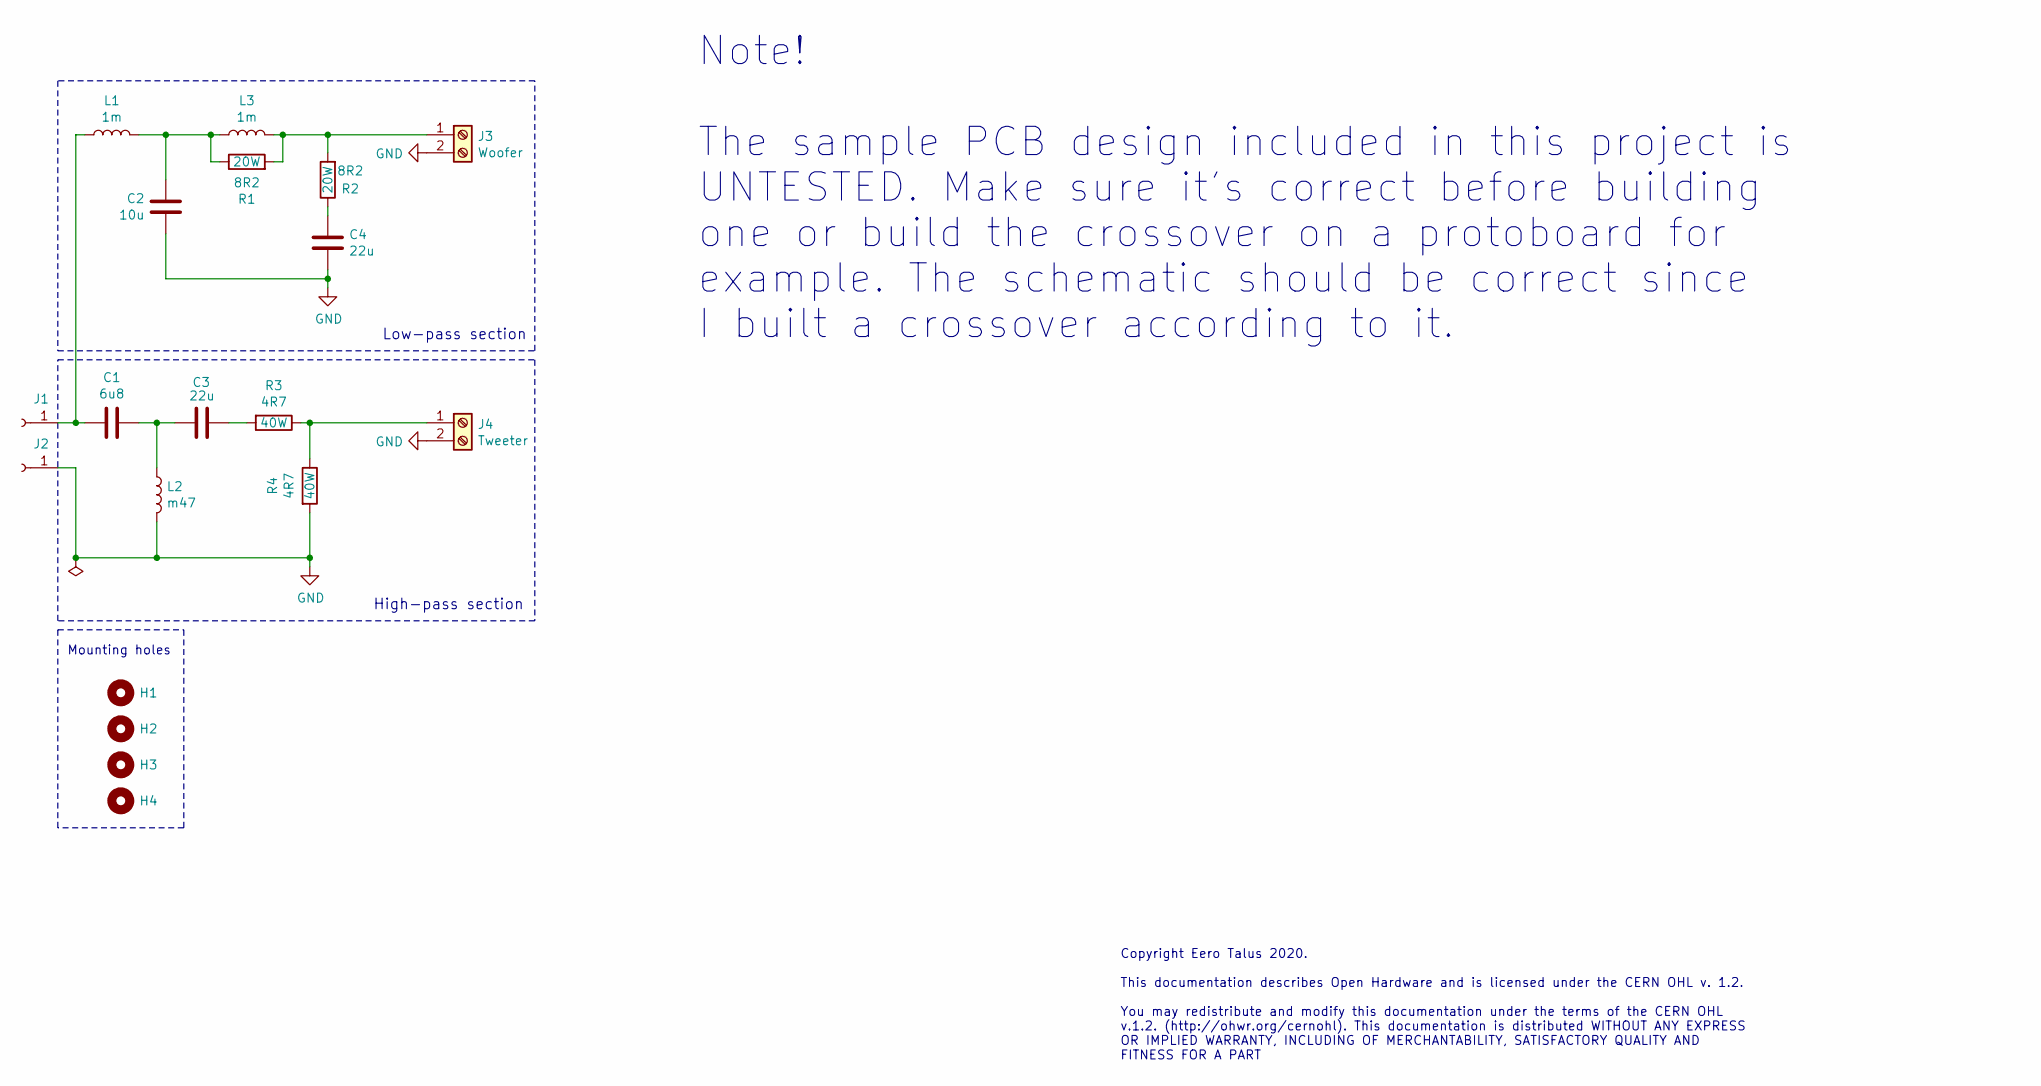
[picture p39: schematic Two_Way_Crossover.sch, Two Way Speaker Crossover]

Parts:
C1: 6u8; C_Rect_L31.5mm_W11.0mm_P27.50mm_MKS4
C2: 10u; C_Rect_L26.5mm_W8.5mm_P22.50mm_MKS4
C3, C4: 22u; C_Rect_L31.5mm_W15.0mm_P27.50mm_MKS4
H1, H2, H3, H4: MountingHole; MountingHole_3.2mm_M3_DIN965
J1, J2: Conn_01x01_Female; MountingHole_3.2mm_M3_DIN965_Pad
J3: Woofer; CTBP0508_x2_10.16x8.5x10.20mm_P5.08mm
J4: Tweeter; CTBP0508_x2_10.16x8.5x10.20mm_P5.08mm
L1, L3: 1m; Radial_D36.5mm_H12.0mm_P23.0mm
L2: m47; Radial_D36.5mm_H12.0mm_P23.0mm
R1, R2: 8R2; R_Axial_Power_L60.0mm_W14.0mm_P66.04mm
R3, R4: 4R7; Resistor_Power_Axial_L91.5_W20.2_H20.2

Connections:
GND: C2.1, C4.2, J2.1, J3.2, J4.2, L2.2, R4.2
unnamed: C1.1, C3.1, L2.1
unnamed: C1.2, J1.1, L1.1
unnamed: C2.2, L1.2, L3.1, R1.1
unnamed: C3.2, R3.2
unnamed: C4.1, R2.1
unnamed: J3.1, L3.2, R1.2, R2.2
unnamed: J4.1, R3.1, R4.1

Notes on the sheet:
Mounting holes
Low-pass section
High-pass section
Copyright Eero Talus 2020. This documentation describes Open Hardware and is licensed under the CERN OHL v. 1.2. You may redistribute and modify this documentation under the terms of the CERN OHL v.1.2. (http://ohwr.org/cernohl). This documentation is distributed WITHOUT ANY EXPRESS OR IMPLIED WARR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
Note! The sample PCB design included in this project is UNTESTED. Make sure it's correct before building one or build the crossover on a protoboard for example. The schematic should be correct since I built a crossover according to it.

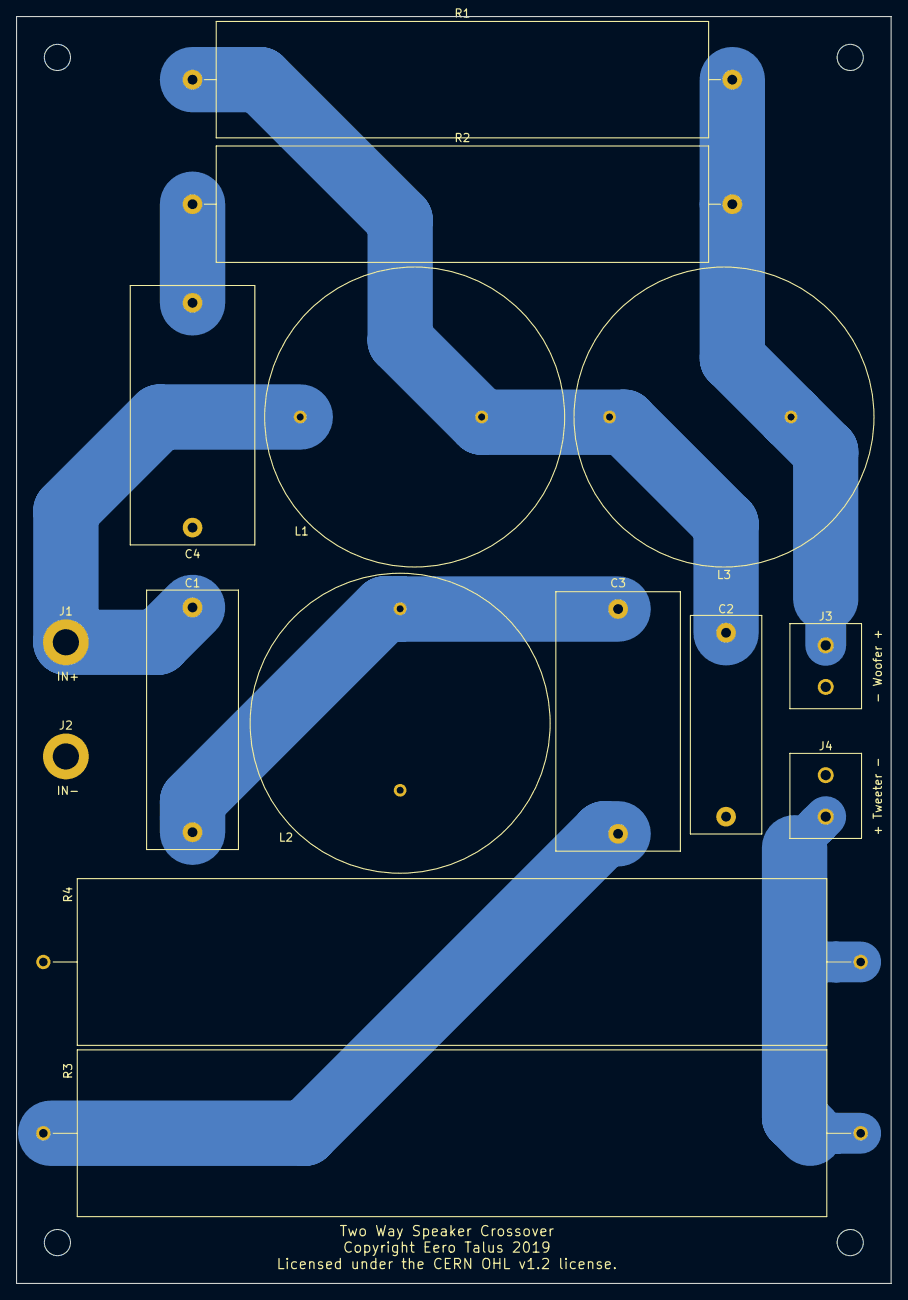
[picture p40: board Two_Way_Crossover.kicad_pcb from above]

Board: 2 copper layers, 107.0 x 155.0 mm, 19 parts (0 on the bottom side), 8 nets.

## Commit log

2019-07-30 Model tweeter and cutouts
    [model.FCStd]
2019-08-02 Various improvements
    [model.FCStd]
2019-08-04 Add threaded inserts
2019-08-05 Improve driver positions
2019-08-05 Model a connector panel
2019-08-05 Improve model, add BOM
    [BOM.ods]
2019-08-09 Various tweaks
    [BOM.ods]
2019-08-13 Model a jig for routing the port slot
2019-08-13 Change back and front panel thickness from 20mm to 18mm
2019-09-15 Begin modeling a speaker stand
    [stand.FCStd]
2019-09-17 Change speaker stand leg angles to 12.5deg
    [stand.FCStd]
2019-10-14 Tweak port design
    [mold.FCStd, stand.FCStd]
2019-11-29 Improve directory layout, generate documentation pdf with sh
    [mold.FCStd, stand.FCStd]
2019-11-30 Create proper crossover schematics & PCB + fix ngspice resistor values
    [Two_Way_Crossover.kicad_pcb, Two_Way_Crossover.sch]
2019-12-12 Tweak crossover
    [Two_Way_Crossover.kicad_pcb]
2019-12-12 Model a new stand
    [stand_2.FCStd]
2019-12-15 Model yet another stand
    [stand_3.FCStd]
2019-12-16 Redesign PCB
    [Two_Way_Crossover.kicad_pcb, Two_Way_Crossover.sch]
2019-12-16 Improve stand model
    [stand_3.FCStd]
2019-12-18 Create CAM operations for stand plates
    [stand_3.FCStd]
2019-12-18 Fix CAM feedrates and spindle speeds
    [stand_3.FCStd]
2019-12-19 Partially fix incorrect PCB footprints
    [Two_Way_Crossover.kicad_pcb, Two_Way_Crossover.sch]
2019-12-31 Modify stand details
    [stand_3.FCStd]
2020-01-01 Improve docs
    [stand.FCStd, stand_2.FCStd]
2020-01-01 Tweak stand model CAM settings
    [stand.FCStd, stand_3.FCStd]
2020-01-06 Remove stand model from repo
    [stand.FCStd]
2020-01-07 Add license
    [Two_Way_Crossover.kicad_pcb, Two_Way_Crossover.sch]
